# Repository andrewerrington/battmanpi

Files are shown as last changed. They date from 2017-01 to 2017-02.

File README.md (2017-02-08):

# BattManPi
A project to redesign Stefan Vorkoetter's BattMan II for Raspberry Pi:  
http://www.stefanv.com/electronics/battman2.html

BattMan II is a computer-controlled battery manager which can be used
to charge and discharge common types of rechargeable batteries.

The original project used a Borland C++ program under Windows to drive
the hardware through the PC LPT port.  These days LPT ports are rare, and
no-one has updated the software to use another interface method such as
a USB GPIO module.

There are three aspects to this project.  First, redesign the circuit to
operate with the Raspberry Pi 3.3V GPIO levels.  Second, lay out a new
PCB for the new circuit.  Third, translate the Borland C++ code to
something that will run on the Pi.

The first phase is addressed by the schematic found in the project files
here.  The schematic was drawn using KiCAD, which was then used to do
the PCB artwork for the second phase.  For the third phase, the original
C++ code has been converted to Python with a TKinter GUI.  Permission has
been granted to release the new code under the GPL.  This does not
affect the license of the original code.

At the time of writing the schematic, PCB artwork, and software are ready
for testing.  The PCB has not been fabricated, so the circuit and the
software have not been tested.  I hope to have time to do this in April
or May 2017.

The original design is copyright Stefan Vorkoetter 2007.

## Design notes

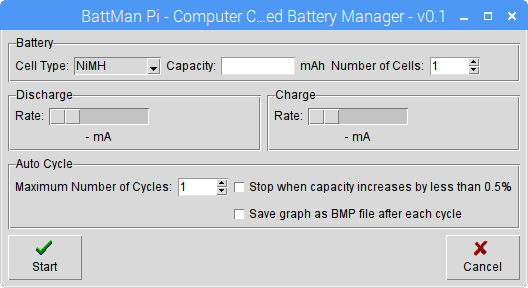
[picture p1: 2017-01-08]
screenshots/start_screen.png

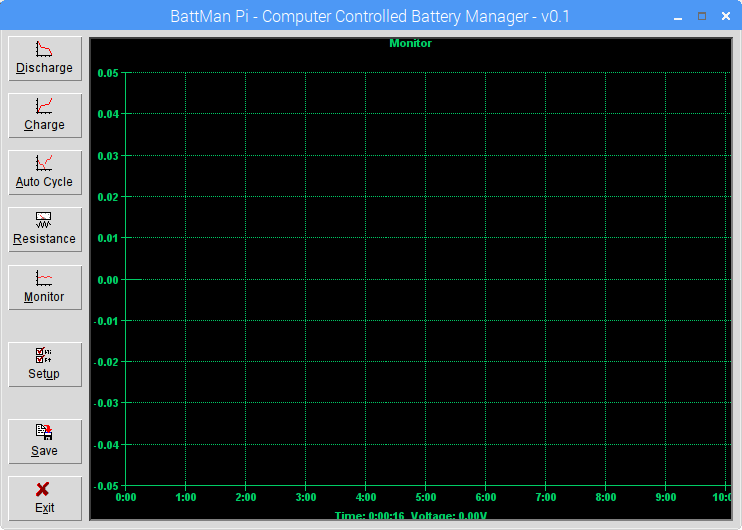
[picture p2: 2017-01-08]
screenshots/main_screen.png

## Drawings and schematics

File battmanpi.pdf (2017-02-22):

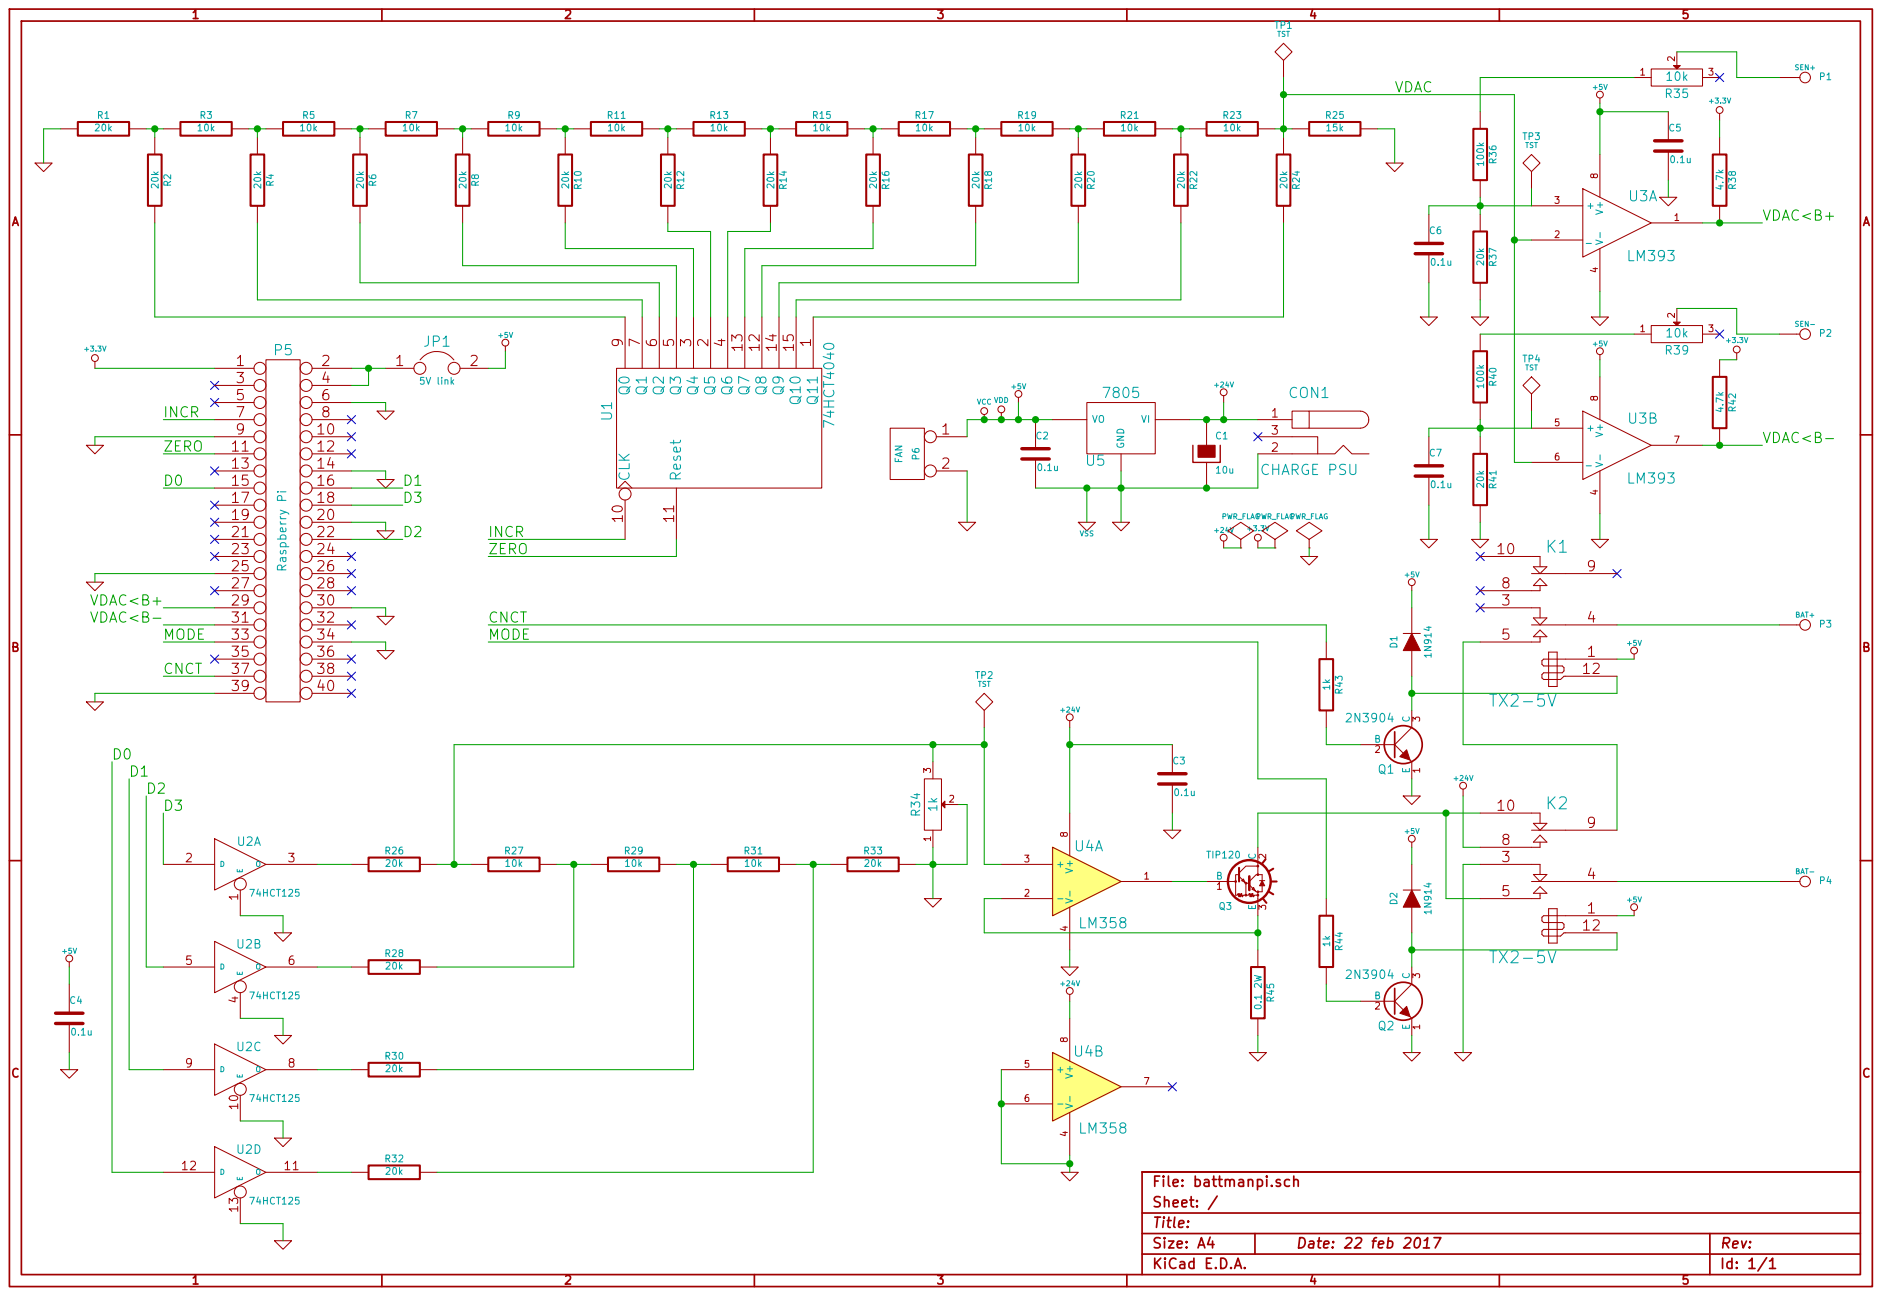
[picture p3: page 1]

Id: 1/1 Title: File: battmanpi.sch

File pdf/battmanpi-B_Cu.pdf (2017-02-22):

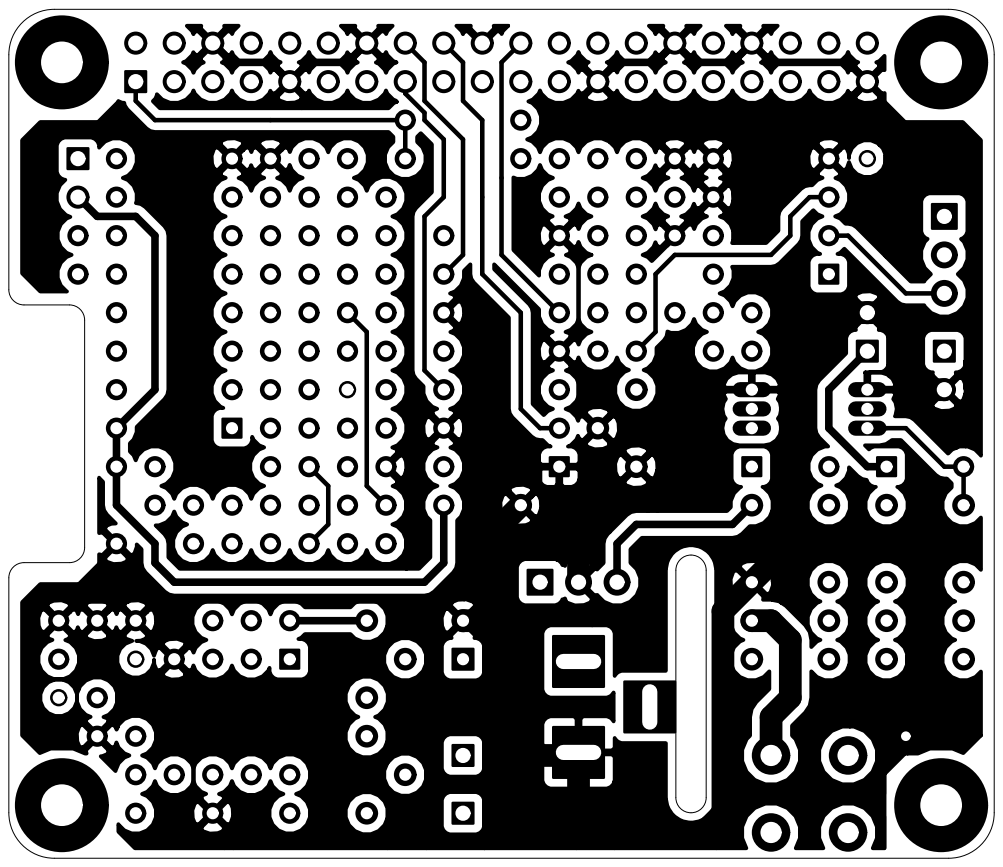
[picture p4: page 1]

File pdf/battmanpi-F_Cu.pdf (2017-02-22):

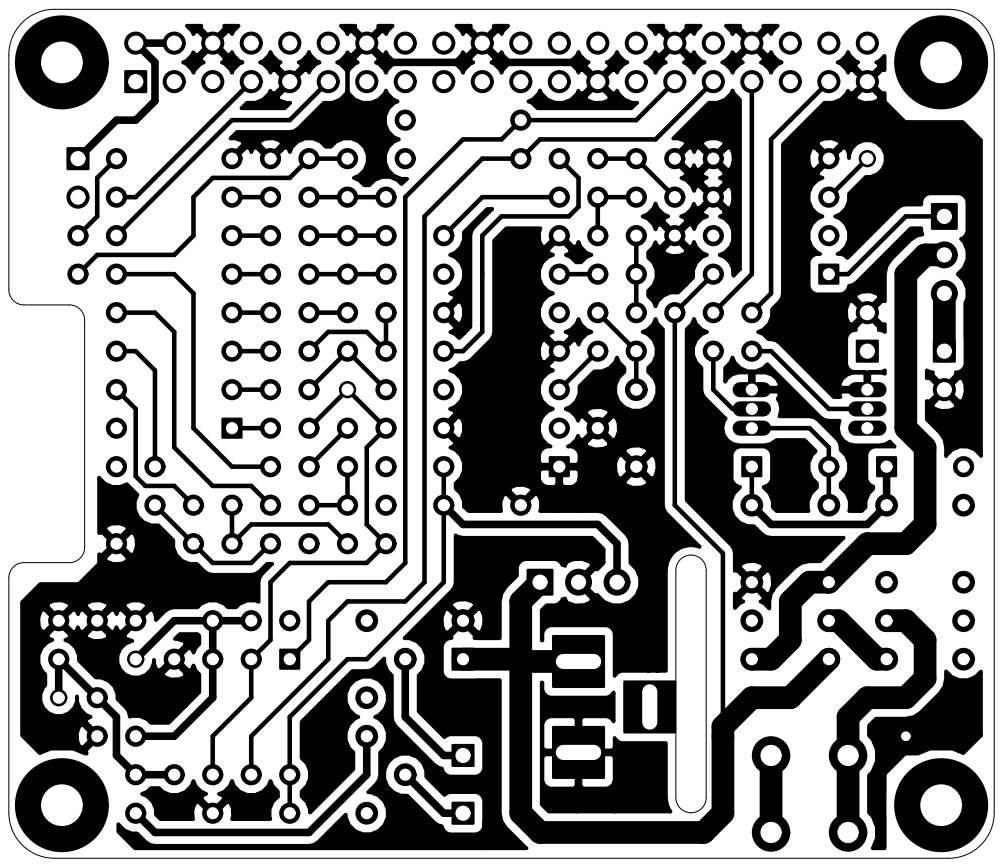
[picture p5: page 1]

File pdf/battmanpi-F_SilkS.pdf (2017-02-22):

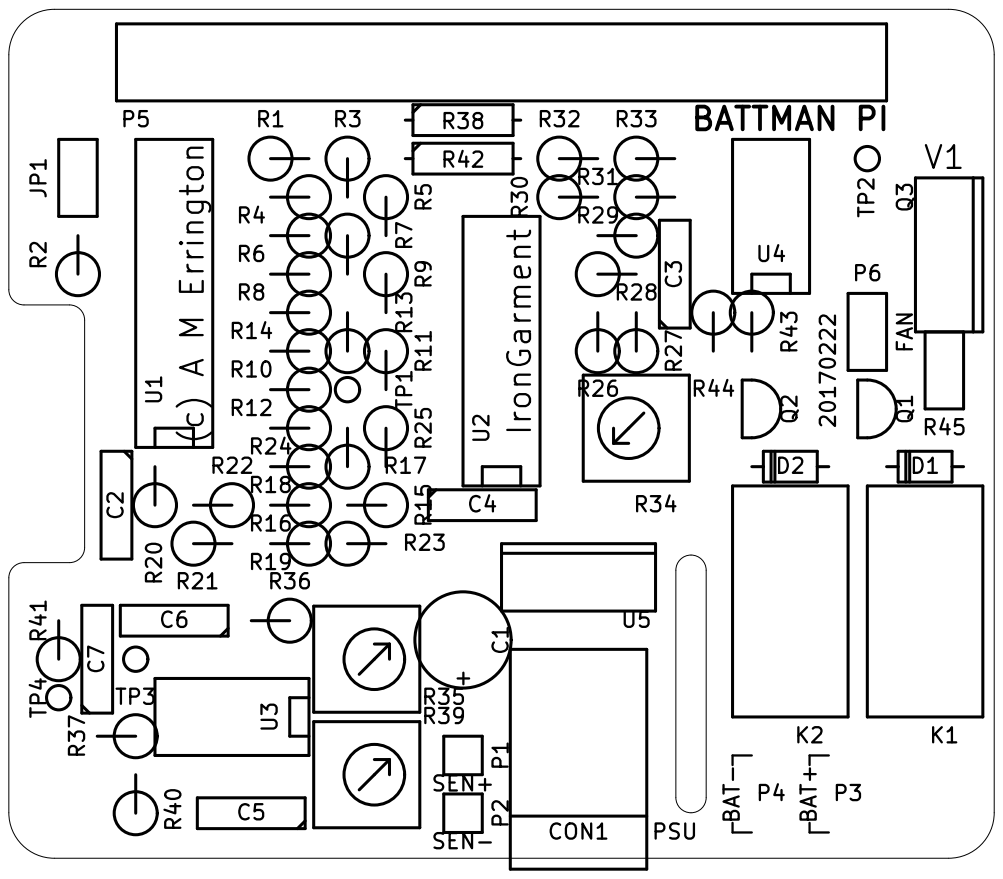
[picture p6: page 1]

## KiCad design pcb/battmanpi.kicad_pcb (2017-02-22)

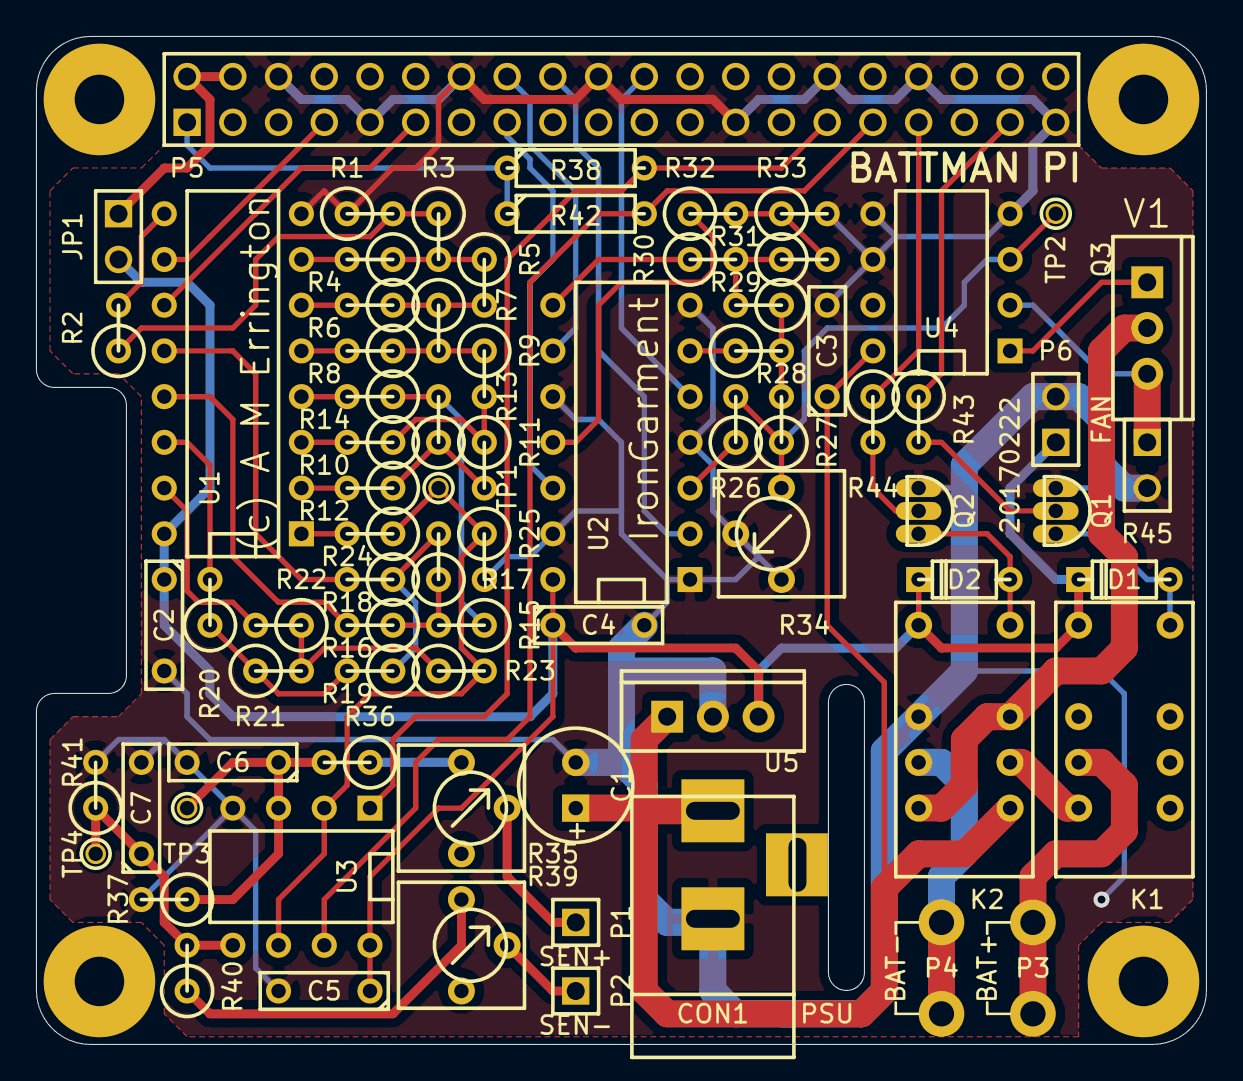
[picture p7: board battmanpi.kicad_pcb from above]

Board: 2 copper layers, 65.0 x 56.0 mm, 80 parts (0 on the bottom side), 63 nets.

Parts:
C1: 10u; C1V7
C2, C3, C4, C5, C6, C7: 0.1u; C2
CON1: PSU; BARREL_JACK
D1, D2: 1N914; D3S
JP1: 5V link; PIN_ARRAY_2X1
K1, K2: TX2-5V; RELAY_FORMC
P1: SEN+; PIN_ARRAY_1
P2: SEN-; PIN_ARRAY_1
P3: BAT+; 635mmspade
P4: BAT-; 635mmspade
P5: Raspberry Pi; PIN_ARRAY_20X2
P6: FAN; PIN_ARRAY_2X1
Q1, Q2: 2N3904; TO92bulk
Q3: TIP120; TO220V
R1, R2, R4, R6, R8, R10, R12, R14, R16, R18, R20, R22, R24, R26, R28, R30, R32, R33, R37, R41: 20k; R1
R3, R5, R7, R9, R11, R13, R15, R17, R19, R21, R23, R27, R29, R31: 10k; R1
R25: 15k; R1
R34: 1k; 6mmSQ
R35, R39: 10k; 6mmSQ
R36, R40: 100k; R1
R38, R42: 4.7k; R3
R43, R44: 1k; R1
R45: 0.1 2W; PIN_ARRAY_2X1
TP1, TP2, TP3, TP4: TST; PINTST
U1: 74HCT4040; DIP-16__300
U2: 74HCT125; DIP-14__300
U3: LM393; DIP-8__300
U4: LM358; DIP-8__300
U5: 7805; TO220V
mounting_hole: VAL**; mounting_hole
mounting_hole#2, mounting_hole#3, mounting_hole#4: VAL**; mounting_hole

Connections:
+3.3V: P5.1, R38.1, R42.1
+5V: C2.1, C4.1, C5.1, D1.2, D2.2, JP1.2, K1.1, K2.1, P6.1, U1.16, U2.14, U3.8, U5.3
+24V: C1.1, C3.1, CON1.1, K2.8, U4.8, U5.1
/CNCT: P5.37, R43.1
/D0: P5.15, U2.12
/D1: P5.16, U2.9
/D2: P5.22, U2.5
/D3: P5.18, U2.2
/INCR: P5.7, U1.10
/MODE: P5.33, R44.1
/VDAC: R23.2, R24.1, R25.1, TP1.1, U3.2, U3.6
/VDAC<B+: P5.29, R38.2, U3.1
/VDAC<B-: P5.31, R42.2, U3.7
/ZERO: P5.11, U1.11
GND: C1.2, C2.2, C3.2, C4.2, C5.2, C6.2, C7.2, CON1.2, K2.3, P5.6, P5.9, P5.14, P5.20, P5.25, P5.30, P5.34, P5.39, P6.2, Q1.1, Q2.1, R1.1, R25.2, R33.2, R34.1, R34.2, R37.2, R41.2, R45.2, U1.8, U2.1, U2.4, U2.7, U2.10, U2.13, U3.4, U4.4, U4.5, U4.6, U5.2
unnamed: R39.1, R40.1
unnamed: R35.1, R36.1
unnamed: P1.1, R35.2
unnamed: P2.1, R39.2
unnamed: C6.1, R36.2, R37.1, TP3.1, U3.3
unnamed: C7.1, R40.2, R41.1, TP4.1, U3.5
unnamed: R12.2, U1.2
unnamed: R6.2, U1.6
unnamed: R8.2, U1.5
unnamed: R10.2, U1.3
unnamed: R14.2, U1.4
unnamed: R16.2, U1.13
unnamed: R18.2, U1.12
unnamed: R3.2, R4.1, R5.1
unnamed: R9.2, R10.1, R11.1
unnamed: R7.2, R8.1, R9.1
unnamed: R5.2, R6.1, R7.1
unnamed: R20.2, U1.14
unnamed: R1.2, R2.1, R3.1
unnamed: R2.2, U1.9
unnamed: R4.2, U1.7
unnamed: D1.1, K1.12, Q1.3
unnamed: K2.4, P4.1
unnamed: Q1.2, R43.2
unnamed: K1.4, P3.1
unnamed: K1.5, K2.9
unnamed: Q2.2, R44.2
unnamed: R22.2, U1.15
unnamed: R24.2, U1.1
unnamed: D2.1, K2.12, Q2.3
unnamed: K2.5, K2.10, Q3.2
unnamed: JP1.1, P5.2, P5.4
unnamed: R13.2, R14.1, R15.1
unnamed: R11.2, R12.1, R13.1
unnamed: R17.2, R18.1, R19.1
unnamed: R19.2, R20.1, R21.1
unnamed: R21.2, R22.1, R23.1
unnamed: R15.2, R16.1, R17.1
unnamed: R26.2, R27.1, R34.3, TP2.1, U4.3
unnamed: Q3.1, U4.1
unnamed: R31.2, R32.2, R33.1
unnamed: R26.1, U2.3
unnamed: R28.1, U2.6
unnamed: R27.2, R28.2, R29.1
unnamed: R30.1, U2.8
unnamed: R29.2, R30.2, R31.1
unnamed: R32.1, U2.11
unnamed: Q3.3, R45.1, U4.2

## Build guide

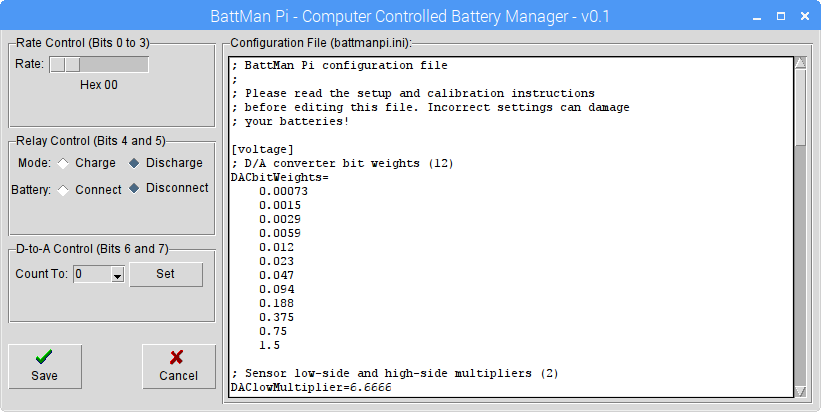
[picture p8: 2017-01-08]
screenshots/setup_screen.png

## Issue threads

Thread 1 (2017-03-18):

PCB v2

andrewerrington, 2017-03-18:
A list of things to consider after PCB v1 has been made and tested.

1 add polarity symbol next to PSU input socket.
2 add footprint for HAT EEPROM, probably on underside of board.

andrewerrington, 2017-03-27:
Add drawings to relay silk screen to show coil and contact configuration.

andrewerrington, 2017-04-16:
Consider adding support for shutdown button on pin 5.

andrewerrington, 2017-05-09:
Add polarity indication on fan header: +FAN-

andrewerrington, 2017-05-09:
Rotate R44 & R43 180°.
Move Q1 away from P6 (FAN).
More space around U5.
Move U1 U2 U3 U4 labels outside footprint.

andrewerrington, 2017-05-09:
Move C6 parallel to C70.

andrewerrington, 2017-05-15:
Move R26 text on silkscreen for visibility.

andrewerrington, 2017-06-21:
Add voltage to 10u cap in BOM.
Add package size to trimmers in BOM.
Add lead spacing to other caps in BOM.

andrewerrington, 2017-06-21:
Consider swapping D2 and D3 GPIO pins to make contiguous group of four IOs.

andrewerrington, 2017-08-29:
Consider placing sense inputs on 0.1" spacing if they aren't already.

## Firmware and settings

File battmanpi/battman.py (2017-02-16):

#!/usr/bin/env python3
"""BattMan Pi main program"""

#
# Copyright 2007 Capable Computing, Inc. (CCI)
# Copyright 2017 Andrew Errington
#
# This file is part of BattMan Pi.
#
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


import tkinter as tk
from tkinter import ttk
from tkinter import filedialog
from tkinter import messagebox

from setup import setupDialog
from start import startDialog

from hardware import battman
from function import func

import graph

import settings

class MainApplication(tk.Tk):
    
    def __init__(self, parent):
        tk.Tk.__init__(self, parent)
        self.parent = parent
        
        self.bm = battman()
        self.func = func(self.parent,self.bm)
        
        self.initialize()
        
    def initialize(self):
        self.appIcon = tk.PhotoImage(data=settings.battmanicon)
        self.call('wm','iconphoto',self._w,self.appIcon)

        self.grid()
        
        self.dischargeIcon=tk.PhotoImage(data=settings.dischargeicon) 
        self.chargeIcon=tk.PhotoImage(data=settings.chargeicon) 
        self.autoCycleIcon=tk.PhotoImage(data=settings.autocycleicon) 
        self.resistanceIcon=tk.PhotoImage(data=settings.resistanceicon) 
        self.monitorIcon=tk.PhotoImage(data=settings.monitoricon) 
        self.setupIcon=tk.PhotoImage(data=settings.setupicon) 
        self.saveIcon=tk.PhotoImage(data=settings.saveicon) 
        self.exitIcon=tk.PhotoImage(data=settings.exiticon)
        self.stopIcon=tk.PhotoImage(data=settings.stopicon)

        self.buttonList=[]

        self.dischargeButton = ttk.Button(self, text="Discharge", underline=0, command=self.discharge, compound=tk.TOP, image=self.dischargeIcon)
        self.dischargeButton.grid(column=1, row=0, sticky=tk.W, padx=6, pady=6)
        self.buttonList.append(self.dischargeButton)
        
        self.chargeButton = ttk.Button(self, text="Charge", underline=0, command=self.charge, compound=tk.TOP, image=self.chargeIcon)
        self.chargeButton.grid(column=1, row=1, sticky=tk.W,padx=6,pady=6)
        self.buttonList.append(self.chargeButton)
        
        self.autoCycleButton = ttk.Button(self, text="Auto Cycle", underline=0, command=self.autoCycle, compound=tk.TOP, image=self.autoCycleIcon)
        self.autoCycleButton.grid(column=1, row=2, sticky=tk.W,padx=6,pady=6)
        self.buttonList.append(self.autoCycleButton)
        
        self.resistanceButton = ttk.Button(self, text="Resistance", underline=0, command=self.resistance, compound=tk.TOP, image=self.resistanceIcon)
        self.resistanceButton.grid(column=1, row=3, sticky=tk.W,padx=6,pady=6)
        self.buttonList.append(self.resistanceButton)
        
        self.monitorButton = ttk.Button(self, text="Monitor", underline=0, command=self.monitor, compound=tk.TOP, image=self.monitorIcon)
        self.monitorButton.grid(column=1, row=4, sticky=tk.W,padx=6,pady=6)
        self.buttonList.append(self.monitorButton)
        
        self.setupButton = ttk.Button(self, text="Setup", underline=3, command=self.setup, compound=tk.TOP, image=self.setupIcon)
        self.setupButton.grid(column=1, row=5, sticky=tk.W, padx=6,pady=26)
        self.buttonList.append(self.setupButton)
        
        self.saveButton = ttk.Button(self, text="Save", underline=0, command=self.save, compound=tk.TOP, image=self.saveIcon)
        self.saveButton.grid(column=1, row=6, sticky=tk.W,padx=6,pady=6)
        self.buttonList.append(self.saveButton)
        
        self.exitButton = ttk.Button(self, text="Exit", underline=1, command=self.exit, compound=tk.TOP, image=self.exitIcon)
        self.exitButton.grid(column=1, row=7, sticky=tk.W,padx=6,pady=6)
        self.buttonList.append(self.exitButton)
        
        self.stopButton = ttk.Button(self, text="Stop", underline=1, command=self.stop, compound=tk.TOP, image=self.stopIcon)
        self.stopButton.grid(column=1, row=0, rowspan=8, sticky=tk.W,padx=6,pady=6)
        self.stopButton.grid_remove()
        
        self.canvas = tk.Canvas(self, bg='black', height=480, width=640, borderwidth=2, relief=tk.SUNKEN)
        self.canvas.grid(column=2, row=0, rowspan=8, sticky=(tk.N, tk.W, tk.E, tk.S), padx=(0,6), pady=6)

        self.func.canvas = self.canvas
        
        self.resizable(False,False)


    def showButtons(self):
        # Show the main buttons (not "Stop")
        for button in self.buttonList:
            button.grid()
        self.stopButton.grid_remove()    


    def hideButtons(self):
        # Hide the main buttons (show only "Stop")
        for button in self.buttonList:
            button.grid_remove()
        self.stopButton.grid()    


    def discharge(self, *args):
        dlg=startDialog(self.parent, title="Discharge Settings", mode='discharge')
        if dlg.result is not None:
            # Start pressed
            settings.stoprequested = False
            self.hideButtons()
            print (dlg.result)
            self.func.PerformDischarge(0, dlg.result)
            self.showButtons()
        else:
            # Cancel pressed
            pass

    
    def charge(self, *args):
        dlg=startDialog(self.parent, title="Charge Settings", mode='charge')
        if dlg.result is not None:
            # Start pressed
            settings.stoprequested = False
            self.hideButtons()
            print (dlg.result)
            self.func.PerformCharge(0, 0, dlg.result)
            self.showButtons()
        else:
            # Cancel pressed
            pass


    def autoCycle(self, *args):
        dlg=startDialog(self.parent, title="Auto Cycle Settings", mode='autocycle')
        if dlg.result is not None:
            # Start pressed
            settings.stoprequested = False
            self.hideButtons()
            print (dlg.result)
            self.func.AutoCycle(dlg.result)
            self.showButtons()
        else:
            # Cancel pressed
            pass


    def resistance(self, *args):
        dlg=startDialog(self.parent, title="Internal Resistance Test Settings", mode='resistance')
        if dlg.result is not None:
            # Start pressed
            settings.stoprequested = False
            self.hideButtons()
            print (dlg.result)
            self.canvas.graph = graph.graph(0,0, self.canvas)
            self.func.CheckImpedance('IMPEDANCE_BOTH', dlg.result)
            del self.canvas.graph
            self.showButtons()
        else:
            # Cancel pressed
            pass
        

    def monitor(self, *args):
        settings.stoprequested = False
        self.hideButtons()
        self.func.MonitorVoltage()
        self.showButtons()
            

    def setup(self, *args):
        dlg=setupDialog(self.parent, title='BattMan Pi Setup Assistant', bm=self.bm)
 

    def stop(self):
        settings.stoprequested = True
        #self.showButtons()


    def save(self, *args):
        try:
            self.canvas.graph
        except AttributeError:
            messagebox.showwarning("BattMan Pi","There is no graph to save.")
            return
            
        fileName = filedialog.asksaveasfilename(title = "Save Graph",
            filetypes = (("Portable Network Graphics","*.png"),
                         ("Windows Bitmap","*.bmp"),
                         ("all files","*.*")))
        if fileName:
            self.canvas.graph.SaveToFile(fileName)
            
            
    def exit(self, *args):
        self.bm.Exit()
        self.quit()


if __name__ == "__main__":
    
    app = MainApplication(None)
    app.title('BattMan Pi - Computer Controlled Battery Manager - v0.1')
    app.mainloop()

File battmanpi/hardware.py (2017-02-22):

#!/usr/bin/env python3
"""BattMan Pi hardware control"""

#
# Copyright 2007 Capable Computing, Inc. (CCI)
# Copyright 2017 Andrew Errington
#
# This file is part of BattMan Pi.
#
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


import time

import RPi.GPIO as GPIO

import settings

class AtoDCalibration:
    def __init__(self):
        self.bitWeights = None
        self.lowMultiplier = None
        self.highMultiplier = None
        

GPIO.setmode(GPIO.BCM)


class battman:

    def __init__(self):

        self.calib = AtoDCalibration()
        self.calib.bitWeights = settings.bitWeights
        
        self.calib.lowMultiplier=settings.DAClowMultiplier
        self.calib.highMultiplier=settings.DAChighMultiplier
        
        # Use BCM numbering for GPIO pins
        # These could be configurable, but probably the BattMan Pi PCB
        # will be used, so the GPIO pins are fixed.  DIY hardware can
        # use different GPIOs, but it's easy to edit the source here.
        
        # Output bits.
        self.DA_RESET = 17
        self.DA_INCREMENT = 4
        self.CONNECT_RELAY = 26
        self.CHARGE_RELAY = 13
        
        #define RATE_MASK 0x0F
        # Rate mask is built bitwise
        self.RATE_MASK_0 = 22   # lsb
        self.RATE_MASK_1 = 23
        self.RATE_MASK_2 = 25
        self.RATE_MASK_3 = 24   # msb

        # Input bits.
        self.LOW_SENSE = 6
        self.HIGH_SENSE = 5

        GPIO.setup(self.DA_RESET, GPIO.OUT, initial=0)
        GPIO.setup(self.DA_INCREMENT, GPIO.OUT, initial=0)
        GPIO.setup(self.CONNECT_RELAY, GPIO.OUT, initial=0)
        GPIO.setup(self.CHARGE_RELAY, GPIO.OUT, initial=0)

        GPIO.setup(self.RATE_MASK_3, GPIO.OUT, initial=0)
        GPIO.setup(self.RATE_MASK_2, GPIO.OUT, initial=0)
        GPIO.setup(self.RATE_MASK_1, GPIO.OUT, initial=0)
        GPIO.setup(self.RATE_MASK_0, GPIO.OUT, initial=0)

        GPIO.setup(self.LOW_SENSE, GPIO.IN)     # No pullup.  Pullup is on PCB.
        GPIO.setup(self.HIGH_SENSE, GPIO.IN)    # No pullup.  Pullup is on PCB.


    def OpenBattMan(self):
        self.CloseBattMan()
        self.StopAndDisconnect()


    def CloseBattMan(self):
        self.StopAndDisconnect()


    def ChargeMode(self, rateCode):
        # Make sure current is off before doing anything.
        self.ZeroCurrent()

        # Turn on relays and give them 100ms to settle.
        GPIO.output(self.CONNECT_RELAY, 1)
        GPIO.output(self.CHARGE_RELAY, 1)

        time.sleep(0.1)

        self.NewChargeRate(rateCode)
        #GPIO.output(self.RATE_MASK_0, rateCode & 0x01)
        #GPIO.output(self.RATE_MASK_1, rateCode & 0x02)
        #GPIO.output(self.RATE_MASK_2, rateCode & 0x04)
        #GPIO.output(self.RATE_MASK_3, rateCode & 0x08)


    def NewChargeRate(self, rateCode):
        # Turn on current.
        #  controlByte += rateCode & RATE_MASK;

        # We can't write a nibble directly, but writing
        # the LSB first should minimise disturbance.
        # controlByte = (controlByte & ~RATE_MASK) | (rateCode & RATE_MASK);
        GPIO.output(self.RATE_MASK_0, rateCode & 0x01)
        GPIO.output(self.RATE_MASK_1, rateCode & 0x02)
        GPIO.output(self.RATE_MASK_2, rateCode & 0x04)
        GPIO.output(self.RATE_MASK_3, rateCode & 0x08)


    def DischargeMode(self, rateCode):
        #  Make sure current is off before doing anything.
        self.ZeroCurrent()

        # Turn on relays and give them 100ms to settle.
        GPIO.output(self.CONNECT_RELAY, 1)
        
        time.sleep(0.1)

        # Turn on current.
        self.NewChargeRate(rateCode)

        # controlByte += rateCode & RATE_MASK;
        #GPIO.output(self.RATE_MASK_0, rateCode & 0x01)
        #GPIO.output(self.RATE_MASK_1, rateCode & 0x02)
        #GPIO.output(self.RATE_MASK_2, rateCode & 0x04)
        #GPIO.output(self.RATE_MASK_3, rateCode & 0x08)


    def StopAndDisconnect(self):
        # Make sure current is off before doing anything.
        self.ZeroCurrent()

        # Turn off relays and give them 100ms to settle.
        GPIO.output(self.CONNECT_RELAY, 0)
        GPIO.output(self.CHARGE_RELAY, 0)

        time.sleep(0.1)


    def ZeroCurrent(self):
        
        GPIO.output(self.RATE_MASK_0, 0)
        GPIO.output(self.RATE_MASK_1, 0)
        GPIO.output(self.RATE_MASK_2, 0)
        GPIO.output(self.RATE_MASK_3, 0)

        time.sleep(0.001)


    def bitsToVolts(self, count, weights):

        v = 0.0

        # Add up the weights corresponding to the 1-bits in count.
        for bit in range(len(weights)):
            if (count & 1):
                v += weights[bit]
            count >>= 1

        return v


    def ReadVoltage(self, calib=None):

        if calib is None:
            calib = self.calib
    
        # Reset 12-bit D-to-A counter and wait 1ms.
        GPIO.output(self.DA_INCREMENT, 0)
        GPIO.output(self.DA_RESET, 1)
        time.sleep(0.001)
        GPIO.output(self.DA_RESET, 0)
        time.sleep(0.001);
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

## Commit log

2016-12-19 First commit (schematic and BOM)
2017-01-07 Added a draft of the PCB layout.
2017-01-07 Updated schematic.
2017-02-01 First draft of application framework.
2017-02-01 KiCAD pcb files
    [battmanpi.kicad_pcb, battmanpi.sch]
2017-02-02 Fixing omission of start.py
    [start.py]
2017-02-02 Moved GIF icons into inline base64 encoded strings. Changed dialogs to non-resizable. Fixed range of charge/discharge slider (1-15, not 0-15).
    [battman.py, settings.py, start.py]
2017-02-06 All functions implemented. Next is bugfixing and testing.
    [battman.py, function.py, start.py]
2017-02-08 KiCad project file for PCB design
2017-02-12 Added some KiCad library files
2017-02-16 Updated schematic and PCB artwork.
2017-02-16 Cleaner PCB artwork
2017-02-18 Almost final PCB layout. All holes set to 0.8 or 1.0 mm (except special components and mounting). Next make traces slightly wider.
    [battmanpi.kicad_pcb]
2017-02-19 Updated PCB layout
2017-02-19 Gerber files for PCB manufacture.
2017-02-20 Latest PCB.
2017-02-22 PCB release candidate
2017-02-22 Made ground lines a little thicker
2017-02-22 Updated hardware.py to match GPIO pins on new schematic
2017-02-22 Latest KiCad project files
    [battmanpi.kicad_pcb, battmanpi.sch]

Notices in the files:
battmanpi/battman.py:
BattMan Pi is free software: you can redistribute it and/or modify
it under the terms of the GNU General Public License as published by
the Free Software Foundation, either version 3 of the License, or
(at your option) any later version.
